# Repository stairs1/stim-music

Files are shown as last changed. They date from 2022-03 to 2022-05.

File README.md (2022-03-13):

# StimMusic - Music + GVS

Experience music and vestibular stimulation in sync. Artists can write music with vestibular stimulation channel using a Digital Audio Workstation (DAW) plugin Virtual Studio Technology (VST). A 4-electrode GVS setup allows for stimulation of yaw, pitch, and roll vestibular experience, at various intensities, in sync with music.

## Safety

Nominal: 0 - 4mA @ 9V
Max: 4mA @ 9V

Proper system should have current limiter! Better, multiple redundant current limiter! Don't connect to mains, use a battery!

## Install + Setup

Ubuntu 20 or Mac

Run ESP32s with GVS firmware and hardware setup, GVS to VST Python backend at VST_to_GVS_server_bridge_python, open VST in new track in DAW. Run the steps below to setup each component.

### Backend
1. Setup and activate virtual environment
2. Setup Youtube-dlc globally:
```
sudo wget https://github.com/blackjack4494/yt-dlc/releases/latest/download/youtube-dlc -O /usr/local/bin/youtube-dlc
sudo chmod a+rx /usr/local/bin/youtube-dlc
```
3. Install requirements:
`pip3 install -r requirements.txt`

### Firmware

1. Install Visual Studio Code. `sudo snap install code --classic`
2. Setup Platform IO in visual studio code.
3. Open ./firmware in PlatformIO
4. Flash onto ESP32s with GVS hardware connected.

### VST

1. Install Reaper of Ableton (DAW)
2. Connect MIDI keyboard to DAW
3. Build VST for your system.
4. (LINUX) - see below
5. Install VST in DAW
6. Run VST on track Midi keyboard input

##### Linux setup:

1. Install linux low latency kernel
2. Install JACK: `sudo apt-get install jackd2 qjackctl`
3. Configure JACK to use low latency - https://jackaudio.org/faq/linux_rt_config.html
4. Install m2jmidid `sudo apt-get install a2jmidid`
5. In `qjackctl`, Go to "Setup" -> Set Midi Driver to "seq" -> "Options (tab)" -> "Startup after execute" line: `pacmd set-default-sink jack_out; a2jmidid -e &`
6. Check qjackctl "Connections" -> Midi and ensure Midi keyboard is there.
7. Start JACK -> qjackctl -> Start
8. Set Reaper to use JACK as Audio Device ("Ctrl-P" -> Audio Device -> Set as JACK)
9. Add midi keyboard in reaper.
10. Run the GVS to VST backend server

## Electrode Placement

2 seperate current pathways, so that current doesn't go across the forehead.
   - "Because SDAS and ODAS are applied using two current stimulators (A+/- and B+/-), a part of current emitted from anode A+ may be received by cathode B- when ground-sharing circuits are used. Then, current might not flow as we intended. Therefore, we used isolated current stimulators that were driven by a different battery." 

Each electrode must be able to be cathod or anode.

1. Left mastoid.
2. Right mastoid
3. Left temple
4. Right temple

Ensure there is no current flow from 3 to 4!

## Electrical

3 isolated bipolar circuits, in order to show ensure current flows as expected.

1. Mastoid-mastoid
2. Left mastoid - left temple
3. Right mastoid - right temple

## Subjective Experience 

Yaw, pitch, roll are the primary colors of the vestibular system.

How can we make it feel like we're flying up? Or dropping into the ground? Or accelerating forward so we are pushed back into our chair?

Left roll - 1 cathode, 2 anode 
Right roll - 1 anode, 2 cathod

Front pitch - 1 anode, 3 cathode, 2 anode, 4 cathode
Back pitch - 1 cathod, 3 anode, 2 cathode, 3 anode

Left yaw - 1 cathode, 2 anode, 3 anode, 4 cathode
Right yaw - 1 anode, 2 cathode, 3 cathode, 4 anode

## References

GVS Electrode placement pathways and associated subjective experience: https://www.ncbi.nlm.nih.gov/pmc/articles/PMC4426693/

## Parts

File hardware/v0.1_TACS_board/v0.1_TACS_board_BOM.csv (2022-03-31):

Id | Designator | Package | Quantity | Designation | Supplier and ref
1 | R12,R5 | R_0805_2012Metric | 2 | NC
2 | J4,J3,J2,J1 | TestPoint_Pad_D2.0mm | 4 | Conn_01x01_Male
3 | R7 | R_0402_1005Metric | 1 | R_Bias
4 | R3,R2,R1,R8,R9 | R_0402_1005Metric | 5 | 1k
5 | R10,R11 | R_0402_1005Metric | 2 | R_Sense
6 | D3,D1,D4,D2 | D_SOD-123F | 4 | PMEG2010EH
7 | Q7,Q2,Q3,Q5 | SOT-23 | 4 | BC857
8 | L1 | L_0805_2012Metric | 1 | 10uH
9 | C6,C1,C7 | C_0402_1005Metric | 3 | 4.7uF
10 | C3,C4 | C_0402_1005Metric | 2 | 1uF
11 | Q8,Q1,Q6,Q4 | SOT-23 | 4 | BC847
12 | C2 | C_0402_1005Metric | 1 | 0.001uF
13 | BT1 | BatterySolderOn | 1 | Battery_Cell
14 | R16 | R_0402_1005Metric | 1 | ?????????
15 | R14,R13 | R_0402_1005Metric | 2 | 1
16 | U1 | TSSOP-8_4.4x3mm_P0.65mm | 1 | Opamp_Dual
17 | C5 | C_0603_1608Metric | 1 | 10uF
18 | R15 | R_0402_1005Metric | 1 | ???????
19 | U2 | Electrode_Solder_Pads | 1 | Electrodes
20 | R4 | R_0402_1005Metric | 1 | 4.7k
21 | U3 | SOT-23-6 | 1 | LT3467AES6TRPBF
22 | R6 | R_0402_1005Metric | 1 | R_bias

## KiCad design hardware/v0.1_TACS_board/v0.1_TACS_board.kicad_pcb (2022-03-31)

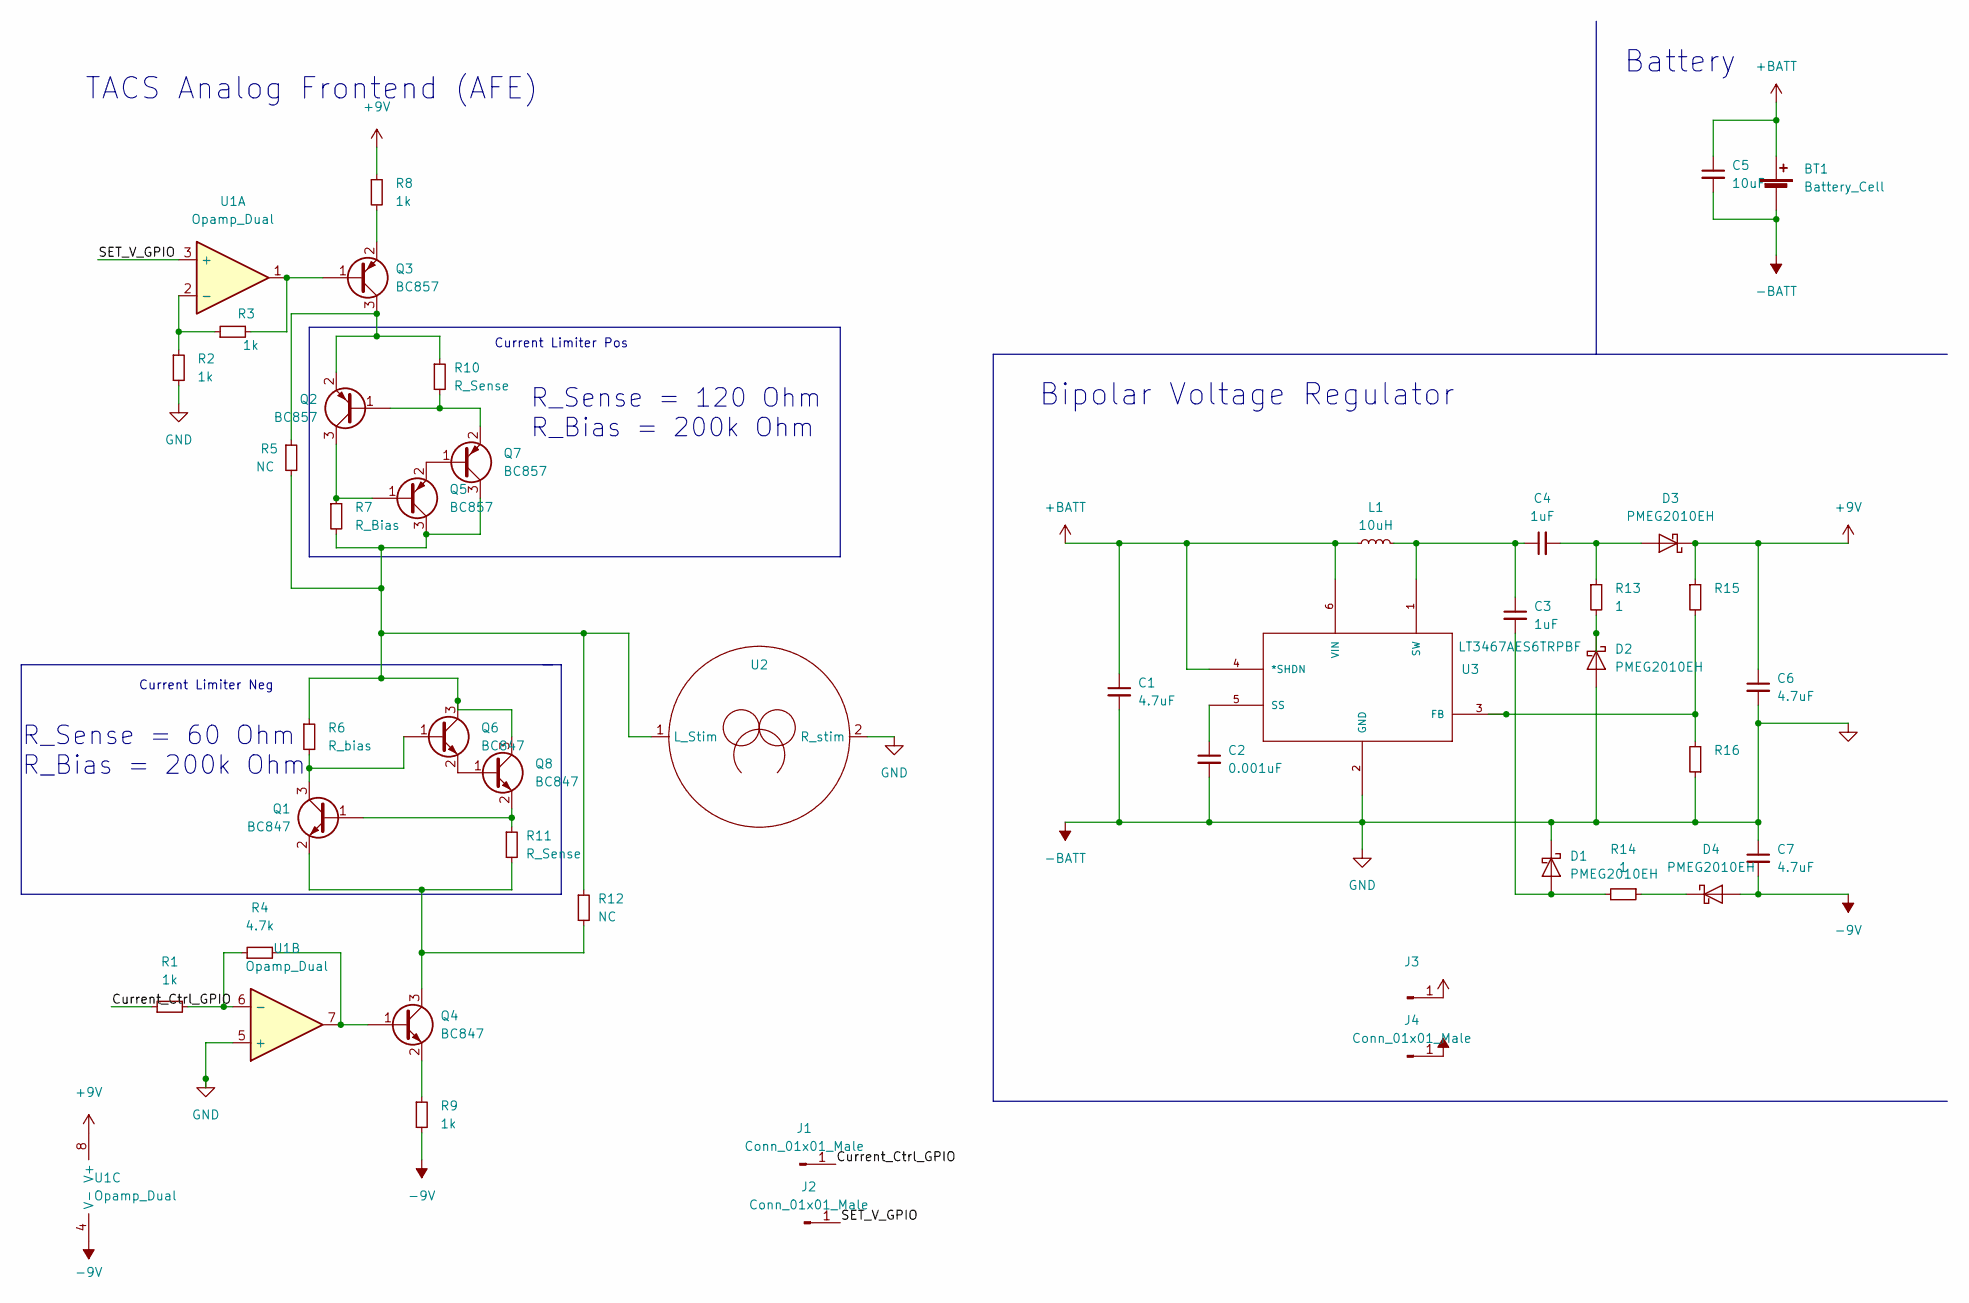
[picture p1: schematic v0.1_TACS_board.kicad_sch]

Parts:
BT1: Battery_Cell; BatterySolderOn
C1, C6, C7: 4.7uF; C_0402_1005Metric
C2: 0.001uF; C_0402_1005Metric
C3, C4: 1uF; C_0402_1005Metric
C5: 10uF; C_0603_1608Metric
D1, D2, D3, D4: PMEG2010EH; D_SOD-123F
J1, J2, J4: Conn_01x01_Male; TestPoint_Pad_D2.0mm
J3: (no value)
L1: 10uH; L_0805_2012Metric
Q1, Q4, Q6, Q8: BC847; SOT-23
Q2, Q3, Q5, Q7: BC857; SOT-23
R1, R2, R3, R8, R9: 1k; R_0402_1005Metric
R4: 4.7k; R_0402_1005Metric
R5, R12: NC; R_0805_2012Metric
R6: R_bias; R_0402_1005Metric
R7: R_Bias; R_0402_1005Metric
R10, R11: R_Sense; R_0402_1005Metric
R13, R14: 1; R_0402_1005Metric
R15, R16: (no value)
U1: Opamp_Dual; TSSOP-8_4.4x3mm_P0.65mm
U2: Electrode_Solder_Pads
U3: LT3467AES6TRPBF; SOT-23-6; MANUFACTURER_PART_NUMBER lt3467aes6#trpbf

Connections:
+BATT: BT1.1 (+), C1.1, C5.1, L1.1, U3.4 (*SHDN), U3.6 (VIN)
/Current_Ctrl_GPIO: J1.1, R1.1
/SET_V_GPIO: J2.1, U1.3 (+)
unnamed: C2.1, U3.5 (SS)
unnamed: C3.1, C4.1, L1.2, U3.1 (SW)
unnamed: C3.2, D1.2 (A), R14.2
unnamed: C4.2, D3.2 (A), R13.1
unnamed: D2.1 (K), R13.2
unnamed: D4.1 (K), R14.1
unnamed: Q1.1 (B), Q8.2 (E), R11.1
unnamed: Q1.2 (E), Q4.3 (C), R11.2, R12.2
unnamed: Q1.3 (C), Q6.1 (B), R6.2
unnamed: Q2.1 (B), Q7.2 (E), R10.2
unnamed: Q2.2 (E), Q3.3 (C), R5.1, R10.1
unnamed: Q2.3 (C), Q5.1 (B), R7.1
unnamed: Q3.1 (B), R3.2, U1.1
unnamed: Q3.2 (E), R8.2
unnamed: Q4.1 (B), R4.2, U1.7
unnamed: Q4.2 (E), R9.1
unnamed: Q5.2 (E), Q7.1 (B)
unnamed: Q5.3 (C), Q6.3 (C), Q7.3 (C), Q8.3 (C), R5.2, R6.1, R7.2, R12.1, U2.1 (L_Stim)
unnamed: Q6.2 (E), Q8.1 (B)
unnamed: R1.2, R4.1, U1.6 (-)
unnamed: R2.1, R3.1, U1.2 (-)
unnamed: R15.2, R16.2, U3.3 (FB)

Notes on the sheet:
TACS Analog Frontend (AFE)
Current Limiter Neg
R_Sense = 60 Ohm R_Bias = 200k Ohm
Battery
Bipolar Voltage Regulator
Current Limiter Pos
R_Sense = 120 Ohm R_Bias = 200k Ohm

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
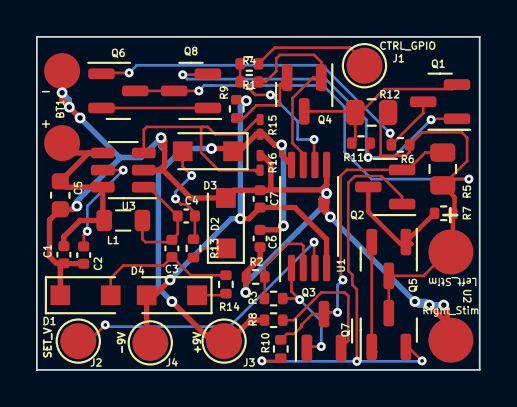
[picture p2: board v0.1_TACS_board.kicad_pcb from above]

Board: 2 copper layers, 24.6 x 18.5 mm, 44 parts (0 on the bottom side), 28 nets.

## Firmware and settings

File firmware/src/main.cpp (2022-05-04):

#include <Arduino.h>
#include <BLEDevice.h>
#include <BLEServer.h>
#include <BLEUtils.h>
#include <string.h>
#include <sstream>
#include <iomanip>
#include <iostream>
#include <string>

using namespace std;

#define SERVICE_UUID "db70e3a8-6cdc-46da-a256-8e1dfedb4bde"
#define CHARACTERISTIC_UUID "49db2ddd-3691-44d3-a0e6-86d2c582ab7e"
#define DESCRIPTOR_UUID "6bdec572-c935-4b09-80de-de3c475d0763"

#define CONST_PIN 26    // D3 on beetle
#define VARIABLE_PIN 25 // D2 on beetle
#define LED_PIN 13      // D7 on beetle
#define STIM_RATE 20    // Hz

const float STIM_PERIOD = 1000 / STIM_RATE; // milliseconds
const int dac_buffer_len = STIM_RATE * 5;   // 5-second buffer capacity (circular)
const int dac_buffer_min = STIM_RATE * 1;   // 1-second ble-stim buffering
const float v_dac_8_bit_const = 255;
const float v_dac_8_bit_high = 141;
const float v_dac_8_bit_low = 186;
int dac_bufffer[dac_buffer_len];
int read_ptr = 0;
int write_ptr = 0;
enum states
{
    idle,
    config_cold,
    config_warm,
    stim_cold,
    stim_warm
};
int state = idle;

void set_state(states new_state)
{
    Serial.printf("Setting State to %d\n", new_state);
    state = new_state;
}

BLEServer *server;

class ServerCallbacks : public BLEServerCallbacks
{
    void onConnect(BLEServer *server)
    {
        Serial.println("connected");
    };

    void onDisconnect(BLEServer *server)
    {
        Serial.println("disco-connected");
        server->getAdvertising()->start();
    };
};

class CharacteristicCallbacks : public BLECharacteristicCallbacks
{
    void onWrite(BLECharacteristic *characteristic)
    {
        std::string value = characteristic->getValue();
        if (value == "stim")
        {
            Serial.println("stimulation mode");
            read_ptr = 0;
            write_ptr = 0;
            set_state(states::stim_cold);
        }
        else if (value == "idle")
        {
            Serial.println("inactive mode");
            read_ptr = 0;
            write_ptr = 0;
            set_state(states::idle);
            digitalWrite(LED_PIN, LOW);
            dacWrite(VARIABLE_PIN, 0.5 * (v_dac_8_bit_high - v_dac_8_bit_low) + v_dac_8_bit_low);
        }
        else if (value == "config")
        {
            Serial.println("config mode");
            read_ptr = 0;
            write_ptr = 0;
            set_state(states::config_cold);
        }
        else
        {
            // decode and add to buffer
            // assume each value is 2 hex characters
            for (int i = 0; i < value.length(); i += 2)
            {
                char toConv[3];
                toConv[0] = value[i];
                toConv[1] = value[i + 1];
                toConv[2] = '\n';
                float stimVal = (float)strtol(toConv, 0, 16);

                int dacVal = state == states::config_cold || states::config_warm
                                 ? stimVal
                                 : stimVal / 255.0 * (v_dac_8_bit_high - v_dac_8_bit_low) + v_dac_8_bit_low;

                dac_bufffer[write_ptr] = dacVal;
                write_ptr = (write_ptr + 1) % dac_buffer_len;

                // Return to idle mode instead of overflowing buffer
                if (write_ptr == read_ptr)
                {
                    Serial.println("buffer full, stopping stim");
                    set_state(states::idle);
                }
            }
        }
    };
};

void setup()
{
    Serial.begin(9600);

    // Stim control signal setup
    pinMode(CONST_PIN, OUTPUT);
    pinMode(VARIABLE_PIN, OUTPUT);
    pinMode(LED_PIN, OUTPUT);
    dacWrite(CONST_PIN, v_dac_8_bit_const);

    // Server setup
    BLEDevice::init("Brain Stimulator 0.0.4");
    server = BLEDevice::createServer();
    server->setCallbacks(new ServerCallbacks());
    server->getAdvertising()->addServiceUUID(SERVICE_UUID);

    // Service setup
    BLEService *service = server->createService(SERVICE_UUID);

    // Characteristic setup
    BLECharacteristic *characteristic = service->createCharacteristic(
        CHARACTERISTIC_UUID,
        BLECharacteristic::PROPERTY_READ |
            BLECharacteristic::PROPERTY_WRITE);
    characteristic->setCallbacks(new CharacteristicCallbacks());
    BLEDescriptor HiLowOffDescriptor(DESCRIPTOR_UUID);
    HiLowOffDescriptor.setValue("low | med | high");
    characteristic->addDescriptor(&HiLowOffDescriptor);

    // Start
    service->start();
    server->getAdvertising()->start();
}

unsigned long start_time;
unsigned long stims_done = 0;
unsigned long flashes_done = 0;

void loop()
{
    switch (state)
    {
        case idle:
            break;

        case config_cold:
        {
            if (write_ptr > read_ptr + dac_buffer_min)
            {
                set_state(config_warm);
                start_time = millis();
                flashes_done = 0;
            }
            break;
        }
        case config_warm:
        {
            // Return to idle mode if buffer empties - stay in sync or die
            if (read_ptr == write_ptr)
            {
                Serial.println("Buffer emptied - pausing");
                set_state(idle);
                break;
            }

            // stim gradually drifts over time
            // stims_to_do will = 2 when it has drifted more than the sampling period
            int flashes_to_do = static_cast<int>((millis() - start_time) / 1000.0 * STIM_RATE) - flashes_done;
            if (flashes_to_do > 0)
            {
                flashes_done += flashes_to_do;
            }
            else
            {
                delay(STIM_PERIOD / 10);
                break;
            }

            // Write LED and increment read pointer
            int led_value = dac_bufffer[read_ptr] > 128 ? HIGH : LOW;
            Serial.printf("Configure value : %d\n", led_value);
            digitalWrite(LED_PIN, led_value);
            read_ptr = (read_ptr + flashes_to_do) % dac_buffer_len;
            break;
        }
        case stim_cold:
        {
            if (write_ptr > read_ptr + dac_buffer_min)
            {
                set_state(stim_warm);
                start_time = millis();
                stims_done = 0;
            }
            break;
        }
        case stim_warm:
        {
            // Return to idle mode if buffer empties - stay in sync or die
            if (read_ptr == write_ptr)
            {
                Serial.println("Buffer emptied - pausing");
                set_state(idle);
                break;
            }
            // stim gradually drifts over time
            // stims_to_do will = 2 when it has drifted more than the sampling period
            int stims_to_do = static_cast<int>((millis() - start_time) / 1000 * STIM_RATE) - stims_done;
            if (stims_to_do > 0)
            {
                stims_done += stims_to_do;
            }
            else
            {
                delay(STIM_PERIOD / 10);
                break;
            }

            // Write DAC & increment read pointer
            Serial.printf("DAC value: %d\n", dac_bufffer[read_ptr]);
            dacWrite(VARIABLE_PIN, dac_bufffer[read_ptr]);
            read_ptr = (read_ptr + stims_to_do) % dac_buffer_len;
            break;
        }
    }
}

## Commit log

2022-03-08 ESP32 GATT server for stim control
2022-03-08 Add all socket programs
2022-03-08 Add midi number and velocity sending VST code
2022-03-12 backend playing audio, generating stim track from audio, sending stream of stim chunks to stim client while music is playing
2022-03-27 finish schematic of AFE, bipolar regulator, battery supply board, start layout
    [v0.1_TACS_board.kicad_pcb, v0.1_TACS_board.kicad_sch]
2022-03-31 finish board TACS board, generate production files, order on jlcpcb
    [v0.1_TACS_board-B_Cu.gbl, v0.1_TACS_board-B_Mask.gbs, v0.1_TACS_board-B_Paste.gbp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]
2022-04-17 sans-limiter 12V kicad schematic
    [v0.1_TACS_board.kicad_sch]
2022-04-22 SPICE for +- 2V, max 4k head
2022-04-22 dac pin values for wearable test
2022-04-24 stim+audio phase alignment now works - make stim track offset work with positive or negative phase shift
2022-05-07 add UI, audio-stim calibration, improve buffering
2022-05-07 stim track designer
